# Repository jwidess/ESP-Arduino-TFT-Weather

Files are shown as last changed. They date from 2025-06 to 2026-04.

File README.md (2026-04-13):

# ESP-Arduino-TFT-Weather
This project is a simple weather display for utilizing an old MCUFRIEND_kbv 320x240 ILI9341 2.4" TFT Display shield with an Arduino Uno for display driving and an ESP8266 for data collection and Home Assistant Integration.

## Why does this exist?
I wanted to make use of some old hardware that had been collecting dust in my lab. This old 320x240 2.4" TFT Display shield and a handful of Arduino Uno's I'd never end up using, due to todays affordability of more powerful devices, made me realize I had to find something to use these for, otherwise they where going to get e-wasted. The display shield I am using requires both an SPI connection and an 8-bit parallel connection, and if I wanted to use that along with the touchscreen and SD Card interfaces, an ESP wouldn't have enough GPIOs. On-top of this it would be a wiring nightmare! So I decided to stick with using the display shield, well as a shield, and offload the weather data acquisition to a WiFi capable device like the ESP8266. With this setup I could make use of this display, an Arduino Uno and an ESP8266, all of which are becoming outdated nowadays.

## Example Images:
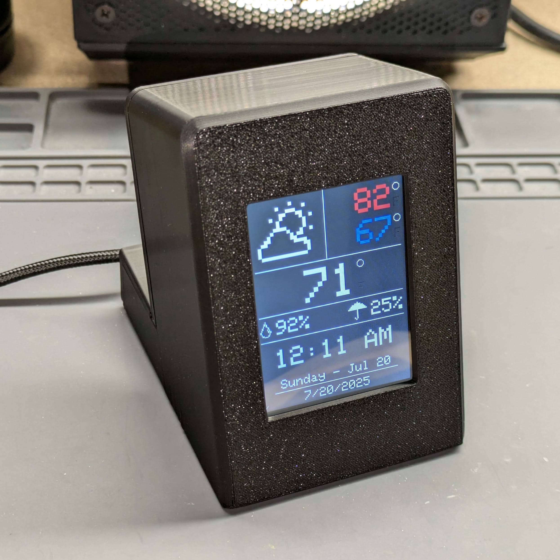
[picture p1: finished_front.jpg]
Front of Device

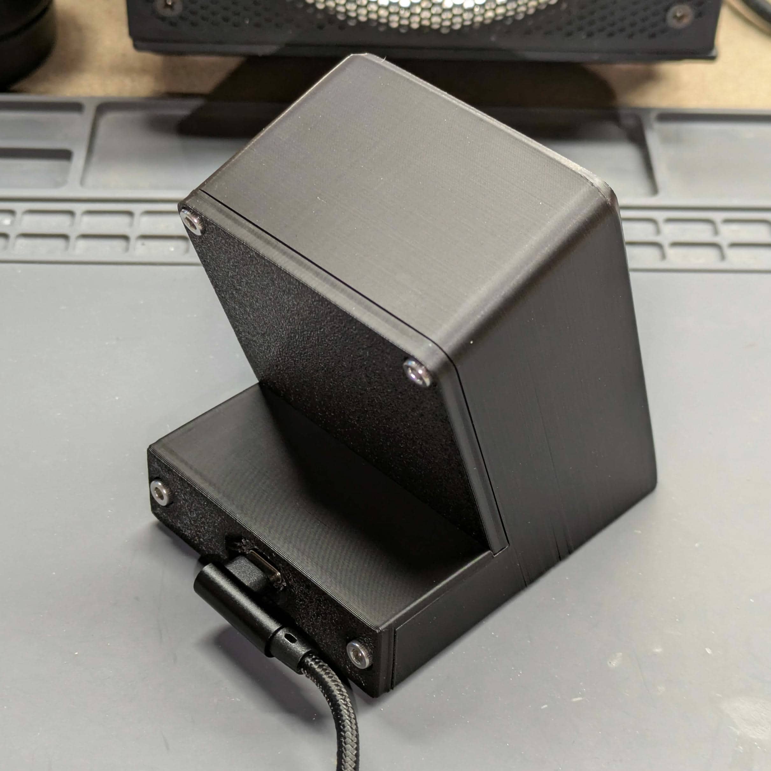
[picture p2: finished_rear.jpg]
Rear of Device


## Full Image Album Here: https://photos.app.goo.gl/iTXBMTu8txQHoKQs9

## Parts List:
- **Electronics:**
  - [MCUFRIEND_kbv 320x240 ILI9341 2.4" TFT Display Shield](https://www.aliexpress.us/item/3256808536298899.html) *(Other varieties may work)*
  - Arduino Uno
  - ESP8266 *(Or ESP32, really anything that runs ESPHome)*
  - [USB-C Breakout](https://www.sparkfun.com/sparkfun-usb-c-breakout.html)
- **3D Printed Parts: - Checkout the Printables Model: https://www.printables.com/model/1363763-weather-display-esp-arduino-24-tft-home-assistant**
  - Enclosure Main Body
  - Top Lid
  - Bottom Lid
- **Screws:**
  - 4x M3x10mm Screws (Lids)
  - 2x M3x6mm Screws (USB-C Breakout)

## Home Assistant & ESPHome
ESPHome acts as a bridge between Home Assistant and the Arduino weather display. Home Assistant gathers weather data from various sources, formats it using templates, and sends it to the ESP8266 device running ESPHome. The ESP8266 then transmits this data via UART to the Arduino, which updates the TFT display.

**How it works:**
- Home Assistant collects weather data (temperature, humidity, rain chance, condition, etc.) from multiple integrations and sensors. (These will need to be customized however you like, I've provided my `.yaml` files as examples)
- Custom templates in `templates.yaml` format the data into a single UART payload string.
- ESPHome receives this payload as a text sensor and sends it to the Arduino over UART every minute (and on power-up).
- The Arduino parses the UART message and updates the display with the latest weather information.
- Display icons and values are mapped according to the weather condition received from Home Assistant.
- Power to the Arduino and thus display can be controlled via Home Assistant using the ESPHome switch entity. I have pin D6 (GPIO12) connected to a MOSFET to control power. Refer to [Wiring Schematics](#Wiring-Schematic)

## Wiring Schematic:
A screenshot of the simple wiring schematic can be found below,

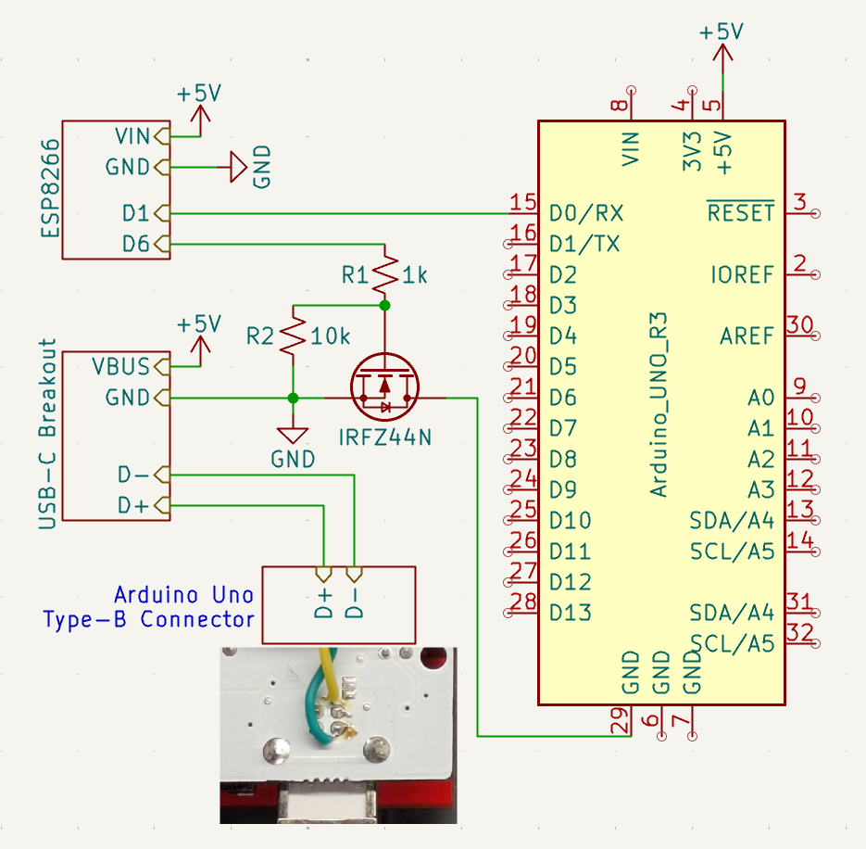
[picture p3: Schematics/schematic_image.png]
Wiring Schematic Image


## UI Design with [Lopaka.app](https://lopaka.app)
The UI was designed using the fantastic [lopaka.app](https://lopaka.app) platform, I highly recommend checking it out. Mikhail has built an incredibly useful and dynamic site. 

## GrabCAD Credits:

My Fusion 360 Archive file contains 3 designs from creators on GrabCAD which I used for designing the enclosure. Please check out these amazing designers at the links below!

1.  [2.4" TFT Display Shield](https://grabcad.com/library/2-4-tft-display-shield-1) - Daniel Barker
2.  [Arduino Uno R3](https://grabcad.com/library/arduino-uno-r3-1) - Andrew\_Whitham
3.  [NodeMcu V3 ESP8266 ESP-12E Development Board Lolin](https://grabcad.com/library/nodemcu-v3-esp8266-esp-12e-development-board-lolin-1) - Enes Sert

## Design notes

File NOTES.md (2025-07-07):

# Project Notes!
General unorganized project notes.

## To-Do:
- Use AccuWeather `sensor.home_condition_day_0` as scrolling text of the days weather summary.

## Display Testing Results
**Display Name:** 2.4inch 320x240 TFT LCD Display Module ILI9341 Resistive Touchscreen 8-bit Parallel Interface SD Card Slot for Arduino - AliExpress

Using the [MCUFRIEND_kbv](https://github.com/prenticedavid/MCUFRIEND_kbv) library had by far the best performance compared to other display libraries. Everything was drawn very quickly. 

### 16-bit RGB Color Picker
https://rgbcolorpicker.com/565

## Condition Value Mapping to Bitmaps
Below is a table of all 15 possible values of the `condition` parameter in HA and how they are mapped to the available bitmaps in the `bitmaps.h`

| Condition Value: | Bitmap Displayed: |
| --- | --- |
| clear-night | Moon |
| exceptional | Exceptional |
| cloudy | cloudy |
| sunny | Sunny |
| snowy-rainy | Snow |
| snowy | Snow |
| rainy | Rainy |
| pouring | Rainy |
| hail | Rainy |
| lightning-rainy  | Lightning |
| lightning | Lightning |
| partlycloudy | Cloudy Sunny |
| windy-variant | Cloudy |
| windy | Cloudy |
| fog | Cloudy |

## UART Comms
Example ESP8266 Send: `HIGH:82,LOW:72,TEMP:74,RAIN:15,HUM:47,TIME:10:15 AM,DATE:Monday - Jan 17th,DATETXT:1/17/2025,CLOUD:clear\n`

### Tesing UART RX:
Formatted input and output test:

<details>
<summary>Serial Monitor Output:</summary>

```
---- Sent utf8 encoded message: "HIGH:82,LOW:72,TEMP:74,RAIN:15,HUM:47,TIME:10:15 AM,DATE:Monday - Jan 17th,DATETXT:1/17/2025,CLOUD:clear\n" ----
--- Weather Data ---
TempHIGH_text: 82
TempLOW_text: 72
CurrentTEMP_text: 74
Chance_of_Rain_Number_text: 15%
Humidity_Number_text: 47%
Time_text: 10:15 AM
Week_Month_Day_text: Monday - Jan 17th
Date_text: 1/17/2025
--------------------
---- Sent utf8 encoded message: "HIGH:115,LOW:-15,TEMP:54,RAIN:100,HUM:100,TIME:12:34 PM,DATE:Saturday - Feb 21st,DATETXT:12/11/2029,CLOUD:overcast\n" ----
--- Weather Data ---
TempHIGH_text: 115
TempLOW_text: -15
CurrentTEMP_text: 54
Chance_of_Rain_Number_text: 100%
Humidity_Number_text: 100%
Time_text: 12:34 PM
Week_Month_Day_text: Saturday - Feb 21st
Date_text: 12/11/2029
--------------------
```
</details>

### Touchscreen Calibration
From `MCUFRIEND_kbv`->`TouchScreen_Calibr_native`:
<details>
<summary>Serial Monitor Output:</summary>

```
Typical 30k Analog pullup with corresponding pin
would read low when digital is written LOW
e.g. reads ~25 for 300R X direction
e.g. reads ~30 for 500R Y direction

Testing : (A2, D8) = 25
Testing : (A3, D9) = 32
ID = 0x9341

cx=178 cy=132 cz=449  X, Y, Pressure
cx=182 cy=427 cz=490  X, Y, Pressure
cx=197 cy=806 cz=376  X, Y, Pressure
cx=472 cy=112 cz=687  X, Y, Pressure
cx=479 cy=832 cz=570  X, Y, Pressure
cx=824 cy=99 cz=713  X, Y, Pressure
cx=826 cy=438 cz=712  X, Y, Pressure
cx=833 cy=828 cz=628  X, Y, Pressure

*** COPY-PASTE from Serial Terminal:
const int XP=8,XM=A2,YP=A3,YM=9; //240x320 ID=0x9341
const int TS_LEFT=155,TS_RT=856,TS_TOP=90,TS_BOT=845;

PORTRAIT  CALIBRATION     240 x 320
x = map(p.x, LEFT=155, RT=856, 0, 240)
y = map(p.y, TOP=90, BOT=845, 0, 320)

LANDSCAPE CALIBRATION     320 x 240
x = map(p.y, LEFT=90, RT=845, 0, 320)
y = map(p.x, TOP=856, BOT=155, 0, 240)
```

Output of `LCD_ID_readnew.ino`:

```
Read Special Registers on MCUFRIEND UNO shield
controllers either read as single 16-bit
e.g. the ID is at readReg(0)
or as a sequence of 8-bit values
in special locations (first is dummy)

diagnose any controller
reg(0x0000) 00 00	ID: ILI9320, ILI9325, ILI9335, ...
reg(0x0004) 00 00 00 00	Manufacturer ID
reg(0x0009) 00 00 61 00 00	Status Register
reg(0x000A) 00 08	Get Power Mode
reg(0x000C) 00 06	Get Pixel Format
reg(0x0030) 00 00 00 00 00	PTLAR
reg(0x0033) 00 00 00 00 00 00 00	VSCRLDEF
reg(0x0061) 00 00	RDID1 HX8347-G
reg(0x0062) 00 00	RDID2 HX8347-G
reg(0x0063) 00 00	RDID3 HX8347-G
reg(0x0064) 00 00	RDID1 HX8347-A
reg(0x0065) 00 00	RDID2 HX8347-A
reg(0x0066) 00 00	RDID3 HX8347-A
reg(0x0067) 00 00	RDID Himax HX8347-A
reg(0x0070) 00 00	Panel Himax HX8347-A
reg(0x00A1) 00 00 00 00 00	RD_DDB SSD1963
reg(0x00B0) 00 00	RGB Interface Signal Control
reg(0x00B3) 00 00 1B 1B 1B	Frame Memory
reg(0x00B4) 00 02	Frame Mode
reg(0x00B6) 00 0A 82 27 04	Display Control
reg(0x00B7) 00 06	Entry Mode Set
reg(0x00BF) 00 00 00 00 00 00	ILI9481, HX8357-B
reg(0x00C0) 00 21 00 00 00 00 00 00 00	Panel Control
reg(0x00C1) 00 10 10 10	Display Timing
reg(0x00C5) 00 31	Frame Rate
reg(0x00C8) 00 00 00 00 00 00 00 00 00 00 00 00 00	GAMMA
reg(0x00CC) 00 72	Panel Control
reg(0x00D0) 00 00 00 00	Power Control
reg(0x00D1) 00 00 00 00	VCOM Control
reg(0x00D2) 00 00 00	Power Normal
reg(0x00D3) 00 00 93 41	ILI9341, ILI9488
reg(0x00D4) 00 00 00 00	Novatek
reg(0x00DA) 00 00	RDID1
reg(0x00DB) 00 00	RDID2
reg(0x00DC) 00 00	RDID3
reg(0x00E0) 00 0F 16 14 0A 0D 06 43 75 33 06 0E 00 0C 09 08	GAMMA-P
reg(0x00E1) 00 08 2B 2D 04 10 04 3E 24 4E 04 0F 0E 35 38 0F	GAMMA-N
reg(0x00EF) 00 03 80 02 02 02	ILI9327
reg(0x00F2) 00 02 02 02 02 02 02 02 02 02 02 02	Adjust Control 2
reg(0x00F6) 00 01 00 00	Interface Control
```
</details>

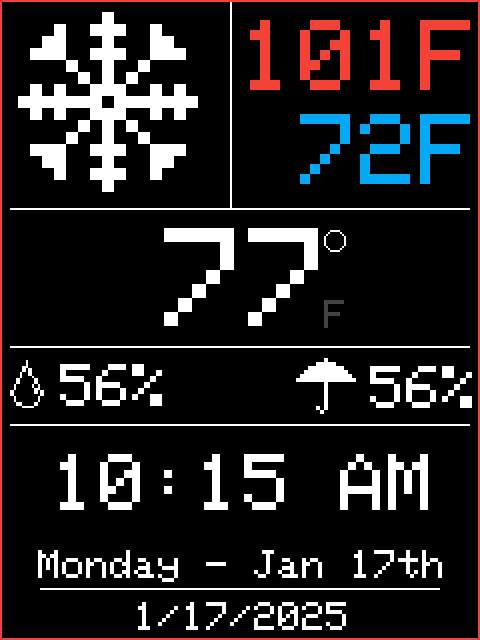
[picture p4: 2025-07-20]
3D Models/Main Enclosure Design/Decal/Display Decal V1.png

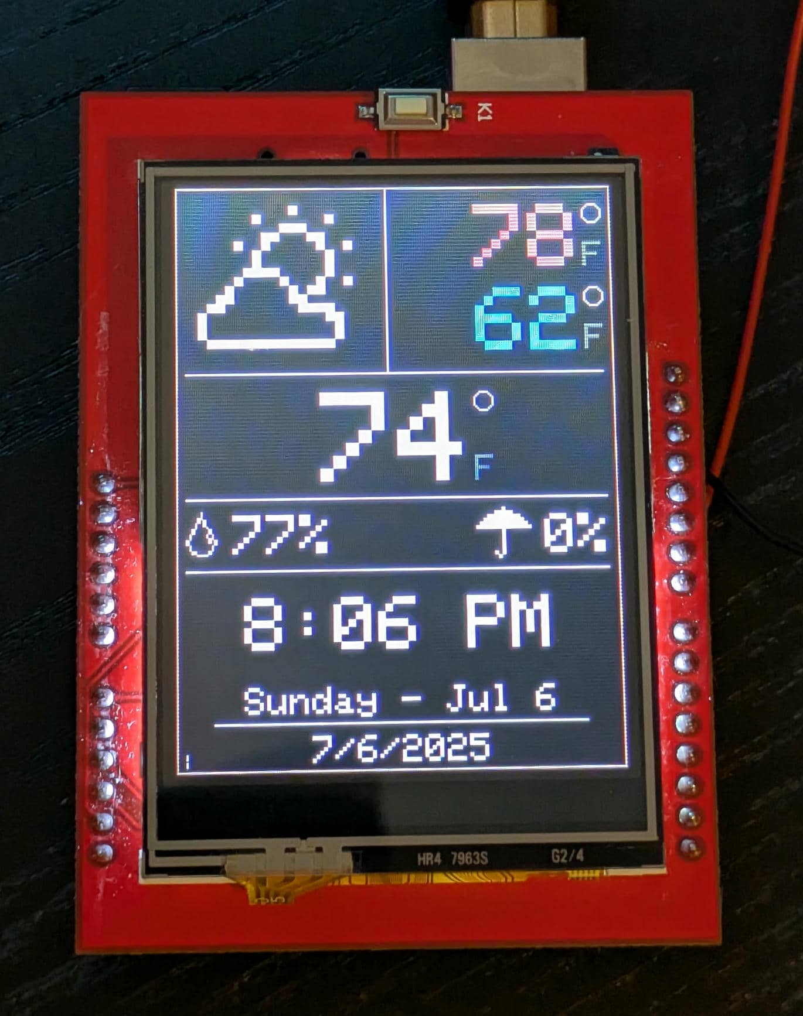
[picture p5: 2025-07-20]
example_image1.jpg

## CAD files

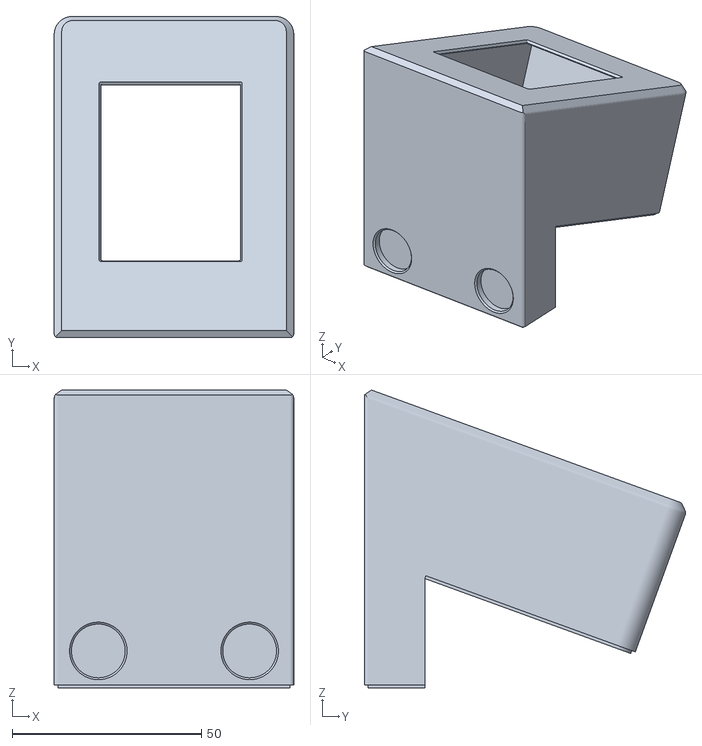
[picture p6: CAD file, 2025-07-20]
3D Models/Main Enclosure Design/Enclosure Main Body V8(v19).stl
63.3 x 85.0 x 78.8

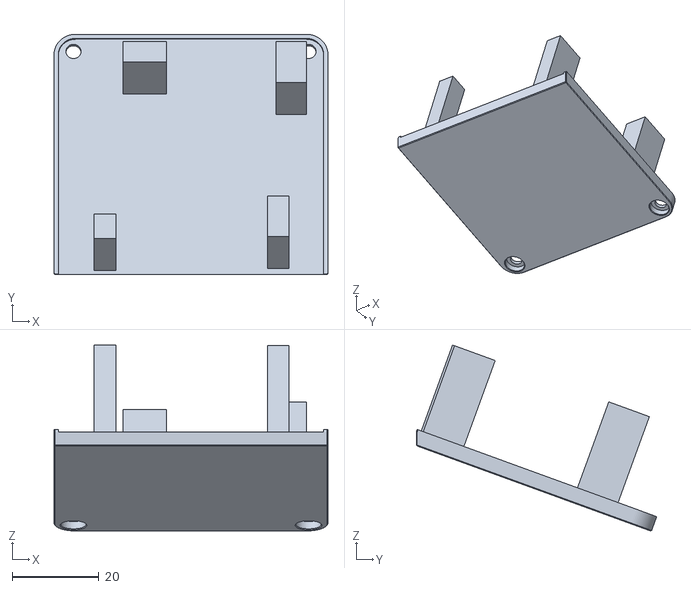
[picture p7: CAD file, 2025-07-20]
3D Models/Main Enclosure Design/Top Lid V2(v15).stl
63.3 x 55.6 x 43.0

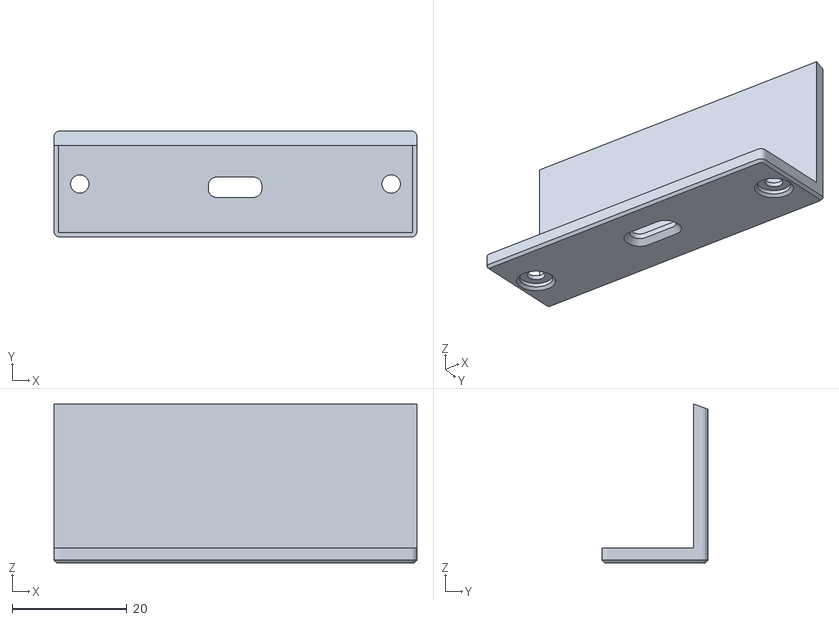
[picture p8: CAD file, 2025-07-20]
3D Models/Main Enclosure Design/Bottom Lid V3(v19).stl
63.3 x 18.5 x 27.7

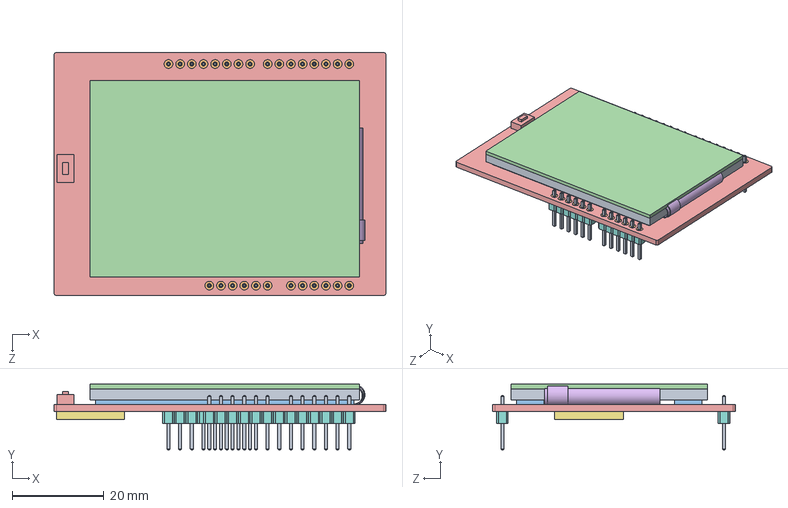
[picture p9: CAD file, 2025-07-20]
3D Models/Grabcad Files/2.4-inch TFT Display Shield V2/2.4_INCH_TFT_DISPLAY_SHIELD_WITH_HEADER.STEP
72.3 x 14.3 x 52.9 mm
2.4INCH_TFT_DISPLAY_SHIELD_FOR_ARDUINO
PIN_HEADER_MALE_2.54MM_PITCH_6 WAY x 2
PIN_HEADER_MALE_2.54MM_PITCH_8 WAY x 2

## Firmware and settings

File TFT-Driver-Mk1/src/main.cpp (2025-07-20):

// TFT-Driver-Mk1
// https://github.com/jwidess/ESP-Arduino-TFT-Weather
// Author: Jwidess
// This sketch is for a 2.4" 320x240 TFT ILI9341 display on an Arduino Uno.
// ==========================================================================

#include <Arduino.h>

#include <Adafruit_GFX.h>
#include <MCUFRIEND_kbv.h>
MCUFRIEND_kbv tft;
#include "bitmaps.h"
#include <SPI.h>

// Assign human-readable names to some common 16-bit color values:
#define BLACK     0x0000
#define GREY      0x73AE
#define DARKGREY  0x2104
#define BLUE      0x001F
#define LIGHTBLUE 0x055E
#define RED       0xf800
#define LIGHTRED  0xfa09
#define GREEN     0x07E0
#define CYAN      0x07FF
#define MAGENTA   0xF81F
#define YELLOW    0xFFE0
#define WHITE     0xFFFF

// 2.4" 320x240 TFT display configuration
#define TFT_WIDTH  240 // Width in pixels
#define TFT_HEIGHT 320 // Height in pixels

/*
#include <TouchScreen.h>
#define MINPRESSURE 200
#define MAXPRESSURE 1000
// Touchscreen configuration
char *name = "2.4 TFT ILI9341";

// From calibration on 6/28/2025
const int   XP = 8, XM = A2, YP = A3, YM = 9; // 240x320 ID=0x9341
const int   TS_LEFT = 155, TS_RT = 856, TS_TOP = 90, TS_BOT = 845;
TouchScreen ts = TouchScreen(XP, YP, XM, YM, 300);

int  pixel_x, pixel_y; // Touch_getXY() updates global vars
bool Touch_getXY(void) {
  TSPoint p = ts.getPoint();
  pinMode(YP, OUTPUT); // restore shared pins
  pinMode(XM, OUTPUT);
  digitalWrite(YP, HIGH); // because TFT control pins
  digitalWrite(XM, HIGH);
  bool pressed = (p.z > MINPRESSURE && p.z < MAXPRESSURE);
  if (pressed) {
    pixel_x = map(p.x, TS_LEFT, TS_RT, 0, tft.width()); //.kbv makes sense to me
    pixel_y = map(p.y, TS_TOP, TS_BOT, 0, tft.height());
  }
  return pressed;
}
*/

// Debug print enable
//! Enabling this adds 11.2% of RAM and 1.5% of flash usage
#define DEBUG_PRINT 0 // Set to 1 to enable debug prints

// Function prototypes
void drawTextCentered(const char *text, int y, int textSize, uint16_t color);
void drawWeatherUI();
void parseWeatherData(const String &input);
void drawStatusIndicator();
void drawTemperatureWithDegreeF(const char *tempStr, int x, int y, int textSize, uint16_t color);
void drawWeatherIconForCloudText();

// Lopaka UI text variables (https://lopaka.app/gallery/10323/21464)
char TempHIGH_text[5] = "HI";
char TempLOW_text[5] = "LO";
char CurrentTEMP_text[5] = "TEMP";
char Chance_of_Rain_Number_text[6] = "RAIN";
char Humidity_Number_text[6] = "HUMID";
char Time_text[12] = "TIME";
char Week_Month_Day_text[32] = "WEEK";
char Date_text[14] = "DATE";
char Cloud_text[20] = "CLOUDY";

// Track last UART RX time. If no UART message is received after 2 minutes, set Time_text to ERROR and raise flag
unsigned long lastUartRx = 0;
bool uartTimeoutFlag = false;

bool minorErrorFlag = false; // Flag for minor errors, e.g. parsing issues

// Status indicator animation state
uint8_t statusAnimIdx = 0;

// ==========================================================================
// Setup & Loop:

void setup(void) {
  Serial.begin(9600);
  uint16_t ID = tft.readID();
  Serial.println("=============================");
  Serial.println("Booting TFT-Driver-Mk1...");
  Serial.print("TFT ID = 0x");
  Serial.println(ID, HEX);
  if (DEBUG_PRINT) Serial.println("!! DEBUG MODE ENABLED !!");
  Serial.println("=============================");
  if (ID == 0xD3D3) ID = 0x9486; // write-only shield
  tft.begin(ID);
  tft.setRotation(0); // PORTRAIT
  tft.fillScreen(BLACK);
  drawWeatherUI();
}

void loop(void) {
  static String input = "";
  static unsigned long lastStatusAnim = 0;
  while (Serial.available()) {
    char c = Serial.read();
    if (c == '\n') {
      parseWeatherData(input);
      drawWeatherUI();
      input = "";
    } else {
      input += c;
    }
  }
  // Check for UART timeout (no message in over 2 minutes)
  if (millis() - lastUartRx > 120000UL) { // 120000ms = 2 minutes
    if (!uartTimeoutFlag) {
      strncpy(Time_text, "ERROR", sizeof(Time_text));
      uartTimeoutFlag = true;
      drawWeatherUI();
    }
  }
  // Animate status indicator every 100ms
  if (millis() - lastStatusAnim > 100) {
    drawStatusIndicator();
    lastStatusAnim = millis();
  }
}

// ==========================================================================
// Functions:

void drawWeatherUI() {
  tft.fillScreen(BLACK); // Clear screen (Not optimal)

  // Outline for centering in enclosure
  if (DEBUG_PRINT) tft.drawRect(0, 0, TFT_WIDTH, TFT_HEIGHT, 0xF206);

  // Cloud Cover Symbol (dynamic)
  drawWeatherIconForCloudText();

  // Vert Divider
  // tft.drawFastVLine(113, 8, 88, WHITE); // Spaced line
  tft.drawFastVLine(115, 1, 103, WHITE); // Fully connected line

  int Deg_F_Offset = 16; // Offset for degree and F when printing in drawTemperatureWithDegreeF
  // TempHIGH (right aligned, 5px padding)
  int tempHIGHLen = strlen(TempHIGH_text);
  int tempHIGHWidth = tempHIGHLen * 6 * 5;
  drawTemperatureWithDegreeF(TempHIGH_text, TFT_WIDTH - tempHIGHWidth - Deg_F_Offset, 10, 5, LIGHTRED);

  // TempLOW (right aligned, 5px padding)
  int tempLowLen = strlen(TempLOW_text);
  int tempLowWidth = tempLowLen * 6 * 5;
  drawTemperatureWithDegreeF(TempLOW_text, TFT_WIDTH - tempLowWidth - Deg_F_Offset, 57, 5, LIGHTBLUE);

  // Above Temp Divider
  // tft.drawLine(5, 104, 234, 104, WHITE);
  tft.drawFastHLine(5, 104, 229, WHITE);

  // Current TEMP
  int currentTempLen = strlen(CurrentTEMP_text);
  int currentTempWidth = currentTempLen * 6 * 7;
  drawTemperatureWithDegreeF(CurrentTEMP_text, (TFT_WIDTH - currentTempWidth) / 2, 115, 7, WHITE);

  // Below Temp Divider
  // tft.drawLine(5, 173, 234, 173, WHITE);
  tft.drawFastHLine(5, 173, 229, WHITE);

  // Humidity Symbol
  tft.drawBitmap(5, 180, image_Humidity_Symbol_bits, 17, 24, WHITE);

  // Humidity Number
  tft.setTextColor(WHITE);
  tft.setTextSize(3);
  tft.setCursor(30, 182);
  tft.print(Humidity_Number_text);

  // Chance of Rain Symbol and Number (right-aligned together)
  tft.setTextSize(3);
  int rainNumLen = strlen(Chance_of_Rain_Number_text);
  int rainNumWidth = rainNumLen * 6 * 3;
  int rainNumRight = 235; // right edge for both symbol and text
  int rainNumX = rainNumRight - rainNumWidth;
  int rainIconWidth = 30;                       // width of the bitmap
  int rainIconX = rainNumX - rainIconWidth - 7; // 7px spacing

  // Determine color based on rain chance
  uint16_t rainColor = WHITE;
  int rainPercent = 0;
  // Extract number value from Chance_of_Rain_Number_text (e.g, "55%")
  // Yes this is a bit hacky, but it works
  char percentStr[4] = {0};
  for (int i = 0, j = 0; Chance_of_Rain_Number_text[i] != '\0' && j < 3; ++i) {
    if (isdigit(Chance_of_Rain_Number_text[i])) {
      percentStr[j++] = Chance_of_Rain_Number_text[i];
    } else {
      break;
    }
  }
  if (percentStr[0] != '\0') {
    rainPercent = atoi(percentStr);
    if (rainPercent >= 50) { rainColor = LIGHTRED; }
  }

  tft.drawBitmap(rainIconX, 177, image_Chance_of_Rain_Symbol_bits, rainIconWidth, 32, rainColor);
  tft.setCursor(rainNumX, 183);
  tft.setTextColor(rainColor);
  tft.print(Chance_of_Rain_Number_text);

  // Below Humid Divider
  // tft.drawLine(5, 212, 234, 212, WHITE);
  tft.drawFastHLine(5, 212, 229, WHITE);

  // Time (centered)
  drawTextCentered(Time_text, 227, 4, uartTimeoutFlag ? RED : WHITE);

  // Week_Month_Day (centered) E.g. "Monday - Jan 17th"
  drawTextCentered(Week_Month_Day_text, 275, 2, WHITE);

  // Date Underline
  // tft.drawLine(20, 294, 219, 294, WHITE);
  tft.drawFastHLine(20, 294, 200, WHITE); // Centered underline

  // Date (centered) E.g. "1/17/2025"
  drawTextCentered(Date_text, 301, 2, WHITE);

  // Draw minor error indicator if needed
  if (minorErrorFlag) {
    tft.fillCircle(232, 312, 4, YELLOW); // Small yellow circle, bottom right
  }
  minorErrorFlag = false; // Reset after drawing
}

// Draw text centered horizontally on the display
// @param text      The string to print
// @param y         The y position (top of text)
// @param textSize  The text size (as used by setTextSize)
// @param color     The 16-bit color value
void drawTextCentered(const char *text, int y, int textSize, uint16_t color) {
  tft.setTextSize(textSize);
  int len = strlen(text);
  int textWidth = len * 6 * textSize;
  int x = (TFT_WIDTH - textWidth) / 2;
  tft.setTextColor(color);
  tft.setCursor(x, y);
  tft.print(text);
}

// Parse UART weather data and update display variables
void parseWeatherData(const String &input) {
  lastUartRx = millis();

  size_t idx = 0;
  String data = input;
  data.trim();
  while (idx < data.length()) {
    int sep = data.indexOf(',', idx);
    String pair = (sep == -1) ? data.substring(idx) : data.substring(idx, sep);
    int colon = pair.indexOf(':');
    if (colon > 0) {
      String key = pair.substring(0, colon);
      String value = pair.substring(colon + 1);
      value.trim();
      if (value.length() == 0) {
        minorErrorFlag = true; // Set error flag if any value is empty
      }
      if (key == "HIGH") {
        value.toCharArray(TempHIGH_text, sizeof(TempHIGH_text));
      } else if (key == "LOW") {
        value.toCharArray(TempLOW_text, sizeof(TempLOW_text));
      } else if (key == "TEMP") {
        value.toCharArray(CurrentTEMP_text, sizeof(CurrentTEMP_text));
      } else if (key == "RAIN") {
        snprintf(Chance_of_Rain_Number_text, sizeof(Chance_of_Rain_Number_text), "%s%%", value.c_str());
      } else if (key == "HUM") {
        snprintf(Humidity_Number_text, sizeof(Humidity_Number_text), "%s%%", value.c_str());
      } else if (key == "TIME") {
        uartTimeoutFlag = false;
        value.toCharArray(Time_text, sizeof(Time_text));
      } else if (key == "DATE") {
        value.toCharArray(Week_Month_Day_text, sizeof(Week_Month_Day_text));
      } else if (key == "DATETXT") {
        value.toCharArray(Date_text, sizeof(Date_text));
      } else if (key == "CLOUD") {
        value.toCharArray(Cloud_text, sizeof(Cloud_text));
      }
    }
    if (sep == -1) break;
    idx = sep + 1;
  }

  if (DEBUG_PRINT) {
    Serial.println("--- UART RX Payload ---");
    Serial.println(input);
    Serial.println("-----------------------");
    // Print formatted values for debugging
    // clang-format off
    Serial.println("--- Weather Data ---");
    Serial.print("TempHIGH_text: "); Serial.println(TempHIGH_text);
    Serial.print("TempLOW_text: "); Serial.println(TempLOW_text);
    Serial.print("CurrentTEMP_text: "); Serial.println(CurrentTEMP_text);
    Serial.print("Chance_of_Rain_Number_text: "); Serial.println(Chance_of_Rain_Number_text);
    Serial.print("Humidity_Number_text: "); Serial.println(Humidity_Number_text);
    Serial.print("Time_text: "); Serial.println(Time_text);
    Serial.print("Week_Month_Day_text: "); Serial.println(Week_Month_Day_text);
    Serial.print("Date_text: "); Serial.println(Date_text);
    Serial.print("Cloud_text: "); Serial.println(Cloud_text);
    Serial.println("--------------------");
    // clang-format on
  }
}

void drawStatusIndicator() {
  // Classic spinner: "|", "/", "-", "\\":
  static const char spinnerChars[4] = {'|', '/', '-', '\\'};
  tft.setTextSize(1);
  tft.setTextColor(WHITE, BLACK); // Draw white on black to erase previous
  tft.setCursor(3, 310);          // Bottom left corner
  tft.print(spinnerChars[statusAnimIdx % 4]);
  statusAnimIdx = (statusAnimIdx + 1) % 4;
}

void drawTemperatureWithDegreeF(const char *tempStr, int x, int y, int textSize, uint16_t color) {
  if (textSize < 3 || textSize > 7) {
    Serial.println("Error: textSize must be between 3 and 7");
    tft.setTextSize(textSize);
    tft.setTextColor(color, BLACK);
    tft.setCursor(x, y);
    tft.print("ERR");
    return;
  }

  int tempLen = strlen(tempStr);
  int charWidth = 6 * textSize; // Each char is 6px wide in Adafruit_GFX
  int totalWidth = tempLen * charWidth;
  int totalHeight = textSize * 7; // Height in pixels based on text size

  // Draw the temperature string
  tft.setTextSize(textSize);
  tft.setTextColor(color, BLACK);
  tft.setCursor(x, y);
  tft.print(tempStr);

  // Calculate where to draw the degree symbol
  int degRadius = 3;  // Default
  uint8_t F_size = 2; // Default size for 'F'
  // clang-format off
  switch (textSize) {
    case 3: degRadius = 3; F_size = 1; break;
    case 4: degRadius = 4; F_size = 1; break;
    case 5: degRadius = 5; F_size = 2; break;
    case 6: degRadius = 5; F_size = 2; break;
    case 7: degRadius = 5; F_size = 2; break;
  }
  // clang-format on

  int degX = x + totalWidth + degRadius; // Small gap after temp
  int degY = y + degRadius;              // Vertically aligned with text

  tft.drawCircle(degX, degY, degRadius, WHITE);

  int F_X = x + totalWidth;                   // Small gap after temp
  int F_Y = (y + totalHeight) - (F_size * 7); // Bottom-aligned with temp text

  tft.setTextSize(F_size);
  tft.setTextColor(DARKGREY, BLACK);

  tft.setCursor(F_X, F_Y);
  tft.print('F');
}

// Struct for weather icon mapping
struct WeatherIconMapping {
  const char *keywords[6]; // Up to 5 keywords, null-terminated
  const uint8_t *bitmap;
  int x, y, w, h;
};

// Icon mappings table
const WeatherIconMapping iconMappings[] = {
    {{"rain", "rainy", "pouring", "hail", nullptr}, image_weather_raining_bits, 14, 10, 85, 80},
    {{"lightning", "lightning-rainy", "thunder", nullptr}, image_weather_lightning_bits, 12, 10, 90, 85},
    {{"snowy", "snowy-rainy", nullptr}, image_weather_snow_bits, 12, 6, 90, 96},
    {{"partlycloudy", "cloudy-sunny", nullptr}, image_weather_cloudy_sunny_bits, 12, 10, 85, 80},
    {{"cloudy", "fog", "windy", "windy-variant", nullptr}, image_weather_cloud_bits, 12, 20, 85, 80},
    {{"exceptional", "unknown", nullptr}, image_weather_exceptional_bits, 12, 6, 90, 90},
    {{"clear-night", "moon", "night", nullptr}, image_weather_moon_bits, 16, 15, 80, 80},
    {{"sunny", "clear", nullptr}, image_weather_sunny_bits, 12, 5, 90, 96},
    {{nullptr}, nullptr, 0, 0, 0, 0} // Sentinel (all null)
};

// Helper function to draw the correct weather icon based on Cloud_text
void drawWeatherIconForCloudText() {
  String cloud = String(Cloud_text);
  cloud.toLowerCase();
  for (int i = 0; iconMappings[i].keywords[0] != nullptr; ++i) {
    for (int k = 0; iconMappings[i].keywords[k] != nullptr; ++k) {
      if (cloud.indexOf(iconMappings[i].keywords[k]) != -1) {
        tft.drawBitmap(iconMappings[i].x, iconMappings[i].y, iconMappings[i].bitmap, iconMappings[i].w, iconMappings[i].h, 0xFFFF);
        return;
      }
    }
  }
  // Default fallback
  tft.drawBitmap(12, 20, image_weather_cloud_bits, 85, 80, 0xFFFF);
  minorErrorFlag = true;
  Serial.println("Warning: Unrecognized cloud text: " + cloud);
}

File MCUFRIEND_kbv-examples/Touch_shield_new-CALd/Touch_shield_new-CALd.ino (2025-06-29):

// the regular Adafruit "TouchScreen.h" library only works on AVRs

// different mcufriend shields have Touchscreen on different pins
// and rotation.
// Run the TouchScreen_Calibr_native sketch for calibration of your shield

#include <MCUFRIEND_kbv.h>
MCUFRIEND_kbv tft;       // hard-wired for UNO shields anyway.
#include <TouchScreen.h>

//const int XP=6,XM=A2,YP=A1,YM=7; //ID=0x9341
//const int TS_LEFT=907,TS_RT=136,TS_TOP=942,TS_BOT=139;

char *name = "2.4 TFT ILI9341";
// From calibration on 6/28/2025
const int XP=8,XM=A2,YP=A3,YM=9; //240x320 ID=0x9341
const int TS_LEFT=155,TS_RT=856,TS_TOP=90,TS_BOT=845;

TouchScreen ts = TouchScreen(XP, YP, XM, YM, 300);
TSPoint tp;

#define MINPRESSURE 200
#define MAXPRESSURE 1000

int16_t BOXSIZE;
int16_t PENRADIUS = 1;
uint16_t ID, oldcolor, currentcolor;
uint8_t Orientation = 0;    //PORTRAIT

// Assign human-readable names to some common 16-bit color values:
#define BLACK   0x0000
#define BLUE    0x001F
#define RED     0xF800
#define GREEN   0x07E0
#define CYAN    0x07FF
#define MAGENTA 0xF81F
#define YELLOW  0xFFE0
#define WHITE   0xFFFF

void show_Serial(void)
{
    Serial.println(F("Most Touch Screens use pins 6, 7, A1, A2"));
    Serial.println(F("But they can be in ANY order"));
    Serial.println(F("e.g. right to left or bottom to top"));
    Serial.println(F("or wrong direction"));
    Serial.println(F("Edit name and calibration statements\n"));
    Serial.println(name);
    Serial.print(F("ID=0x"));
    Serial.println(ID, HEX);
    Serial.println("Screen is " + String(tft.width()) + "x" + String(tft.height()));
    Serial.println("Calibration is: ");
    Serial.println("LEFT = " + String(TS_LEFT) + " RT  = " + String(TS_RT));
    Serial.println("TOP  = " + String(TS_TOP)  + " BOT = " + String(TS_BOT));
    Serial.println("Wiring is always PORTRAIT");
    Serial.println("YP=" + String(YP)  + " XM=" + String(XM));
    Serial.println("YM=" + String(YM)  + " XP=" + String(XP));
}

void show_tft(void)
{
    tft.setCursor(0, 0);
    tft.setTextSize(1);
    tft.print(F("ID=0x"));
    tft.println(ID, HEX);
    tft.println("Screen is " + String(tft.width()) + "x" + String(tft.height()));
    tft.println("");
    tft.setTextSize(2);
    tft.println(name);
    tft.setTextSize(1);
    tft.println("PORTRAIT Values:");
    tft.println("LEFT = " + String(TS_LEFT) + " RT  = " + String(TS_RT));
    tft.println("TOP  = " + String(TS_TOP)  + " BOT = " + String(TS_BOT));
    tft.println("\nWiring is: ");
    tft.println("YP=" + String(YP)  + " XM=" + String(XM));
    tft.println("YM=" + String(YM)  + " XP=" + String(XP));
    tft.setTextSize(2);
    tft.setTextColor(RED);
    tft.setCursor((tft.width() - 48) / 2, (tft.height() * 2) / 4);
    tft.print("EXIT");
    tft.setTextColor(YELLOW, BLACK);
    tft.setCursor(0, (tft.height() * 6) / 8);
    tft.print("Touch screen for loc");
    while (1) {
        tp = ts.getPoint();
        pinMode(XM, OUTPUT);
        pinMode(YP, OUTPUT);
        if (tp.z < MINPRESSURE || tp.z > MAXPRESSURE) continue;
        if (tp.x > 450 && tp.x < 570  && tp.y > 450 && tp.y < 570) break;
        tft.setCursor(0, (tft.height() * 3) / 4);
        tft.print("tp.x=" + String(tp.x) + " tp.y=" + String(tp.y) + "   ");
    }
}


void setup(void)
{
    uint16_t tmp;

    tft.reset();
    ID = tft.readID();
    tft.begin(ID);
    Serial.begin(9600);
    show_Serial();
    tft.setRotation(Orientation);
    tft.fillScreen(BLACK);
    show_tft();

    BOXSIZE = tft.width() / 6;
    tft.fillScreen(BLACK);

    tft.fillRect(0, 0, BOXSIZE, BOXSIZE, RED);
    tft.fillRect(BOXSIZE, 0, BOXSIZE, BOXSIZE, YELLOW);
    tft.fillRect(BOXSIZE * 2, 0, BOXSIZE, BOXSIZE, GREEN);
    tft.fillRect(BOXSIZE * 3, 0, BOXSIZE, BOXSIZE, CYAN);
    tft.fillRect(BOXSIZE * 4, 0, BOXSIZE, BOXSIZE, BLUE);
    tft.fillRect(BOXSIZE * 5, 0, BOXSIZE, BOXSIZE, MAGENTA);

    tft.drawRect(0, 0, BOXSIZE, BOXSIZE, WHITE);
    currentcolor = RED;
    delay(1000);
}

void loop()
{
    uint16_t xpos, ypos;  //screen coordinates
    tp = ts.getPoint();   //tp.x, tp.y are ADC values

    // if sharing pins, you'll need to fix the directions of the touchscreen pins
    pinMode(XM, OUTPUT);
    pinMode(YP, OUTPUT);
    // we have some minimum pressure we consider 'valid'
    // pressure of 0 means no pressing!

    if (tp.z > MINPRESSURE && tp.z < MAXPRESSURE) {
        // most mcufriend have touch (with icons) that extends below the TFT
        // screens without icons need to reserve a space for "erase"
        // scale the ADC values from ts.getPoint() to screen values e.g. 0-239
        //
        // Calibration is true for PORTRAIT. tp.y is always long dimension 
        // map to your current pixel orientation
        switch (Orientation) {
            case 0:
                xpos = map(tp.x, TS_LEFT, TS_RT, 0, tft.width());
                ypos = map(tp.y, TS_TOP, TS_BOT, 0, tft.height());
                break;
            case 1:
                xpos = map(tp.y, TS_TOP, TS_BOT, 0, tft.width());
                ypos = map(tp.x, TS_RT, TS_LEFT, 0, tft.height());
                break;
            case 2:
                xpos = map(tp.x, TS_RT, TS_LEFT, 0, tft.width());
                ypos = map(tp.y, TS_BOT, TS_TOP, 0, tft.height());
                break;
            case 3:
                xpos = map(tp.y, TS_BOT, TS_TOP, 0, tft.width());
                ypos = map(tp.x, TS_LEFT, TS_RT, 0, tft.height());
                break;
        }

        // are we in top color box area ?
        if (ypos < BOXSIZE) {               //draw white border on selected color box
            oldcolor = currentcolor;

            if (xpos < BOXSIZE) {
                currentcolor = RED;
                tft.drawRect(0, 0, BOXSIZE, BOXSIZE, WHITE);
            } else if (xpos < BOXSIZE * 2) {
                currentcolor = YELLOW;
                tft.drawRect(BOXSIZE, 0, BOXSIZE, BOXSIZE, WHITE);
            } else if (xpos < BOXSIZE * 3) {
                currentcolor = GREEN;
                tft.drawRect(BOXSIZE * 2, 0, BOXSIZE, BOXSIZE, WHITE);
            } else if (xpos < BOXSIZE * 4) {
                currentcolor = CYAN;
                tft.drawRect(BOXSIZE * 3, 0, BOXSIZE, BOXSIZE, WHITE);
            } else if (xpos < BOXSIZE * 5) {
                currentcolor = BLUE;
                tft.drawRect(BOXSIZE * 4, 0, BOXSIZE, BOXSIZE, WHITE);
            } else if (xpos < BOXSIZE * 6) {
                currentcolor = MAGENTA;
                tft.drawRect(BOXSIZE * 5, 0, BOXSIZE, BOXSIZE, WHITE);
            }
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

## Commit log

2025-06-29 UART Data Input
    Began work on UART Data Rx and parse. Also added clang format.
2025-06-30 Refactor UI text variables to fixed-size char arrays
    Was running out of memory using `strdup` repeatedly on my static buffers.
    Replaces const char* UI text variables with fixed-size char arrays to avoid dynamic memory allocation and simplify string updates. Updates parseWeatherData to write directly into these arrays instead of using strdup and temporary buffers.
    [main.cpp]
2025-07-01 Add ESPHome config and HA templates.yaml
    Added esp-arduino-tft-weather.yaml for ESP8266-based weather display integration with Home Assistant, including UART payload transmission. Added templates.yaml with Home Assistant template sensors an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
2025-07-01 UART Time update timeout
    If time hasn't been updated in over 2 minutes, error time.
    [main.cpp]
2025-07-01 Status indicator
    Added a simple status indicator to easily tell if the program has crashed.
    [main.cpp]
2025-07-04 Major overhaul
    Reorganized main.cpp to group setup, loop, and function definitions. Added drawTemperatureWithDegreeF() to display temperatures with degree and 'F' symbols based on text size. Updated color definitio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
2025-07-04 Table mapping for drawWeatherIconForCloudText
    Replaced the long if-else chain in drawWeatherIconForCloudText with a mapping table. This change uses 9.3% more RAM, but 2.3% less flash.
    OLD:
    RAM: [===== ] 50.0% (used 1023 bytes from 2048 bytes)
    Flash: [==========] 96.1% (used 31004 bytes from 32256 bytes)
    NEW:
    RAM: [====== ] 59.3% (used 1215 bytes from 2048 bytes)
    Flash: [========= ] 93.8% (used 30258 bytes from 32256 bytes)
    [main.cpp]
2025-07-04 Color rain icon based on chance and add error check
    Rain icon and percentage text now display in LIGHTRED if chance is 50% or higher, otherwise in WHITE. Also adds a check in parseWeatherData to set minorErrorFlag if any weather value is empty.
    [main.cpp]
2025-07-04 Debug print & cleanup
2025-07-07 ESPHomne - Built-in LED Flash on UART Send
2025-07-08 Added switch for display power
    Pin D6 will control a FET that powers the Arduino & TFT Display. This will allow me to turn off the display at night. It also sends the payload on turn on for a quick boot.
2025-07-09 Highest Precipitation Probability Sensor and AccuWeather Source
    Added AccuWeather daily forecast sensors and a new 'Highest Precipitation Probability' sensor that uses the max precipitation probability from multiple sources. Updated the UART Weather Payload to us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
2025-07-20 Enclosure 3D Models
    Added 3D Models for the enclosure including .STL, .STEP, and an F360 Archive.
    [2.4_INCH_TFT_DISPLAY_SHIELD_WITH_HEADER.STEP, Bottom Lid V3(v19).stl, Enclosure Main Body V8(v19).stl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]
2025-07-21 Wiring Schematic
    Added a simple wiring schematic
    [ESP8266.kicad_sch, Type-B.kicad_sch, USB-C_Breakout.kicad_sch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]
2025-07-22 Updated wiring schematic
    [Wiring_V1.kicad_sch]
2025-07-24 Update README.md
    Added credits to GrabCAD creators and link to Printables model.
2025-10-15 Script UART payload sending & update on boot
    Moved UART payload sending into a reusable script 'send_uart_payload' to avoid the duplicates. Also added a WiFi `on_connect` to quickly update the display on first boot.
